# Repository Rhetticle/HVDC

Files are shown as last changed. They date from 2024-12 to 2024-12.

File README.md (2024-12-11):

# HVDC
High voltage DC arc lighter.

<p align="center">
  
  
</p>

<p align="center">
  
</p>

# Topology
HVDC uses a spark-gap style method of arc generation. The two 1uF 1.3kV capacitors are charged until around 600V at which point the 600V gas discharge tube breaks down and the capacitor energy is dumped into the final output transformer primary to generate a high voltage arc on the secondary. 

The first transformer is used to step up the 7.4V supply voltage to 1kV to charge the capacitors. This transformer is driven by a full H-bridge at a 50% duty cycle. Two sqaure wave gate signals are generated by an STM32 microcontroller and two half-bridge gate drivers are used to provide fast switching speeds on the MOSFETs.

HVDC also features a completely embedded battery charging/management system to charge the 2S Lipo battery directly from a micro USB cable.

# Hardware Details
* Microcontroller - STM32C011J6M6 (SOIC8)
* Gate Drivers (Half Bridge) - ADP3110AKRZ-RL (SOIC8)
* Battery Charger - BQ25306RTER (16-WQFN)

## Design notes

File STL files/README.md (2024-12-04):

# Casing
The casing for HVDC was modelled in Fusion 360 and is comprised of three parts namely the bottom piece, top piece and isolating plate. The plate isolates the battery from the potentially high voltage of the output capacitors.

## Casing - Bottom

<p align="center">
  
</p>

## Casing - Top

<p align="center">
  
</p>

# Transformer Insulator

<p align="center">
  
</p>

A insulator was made to hold the transformer to be potted in epoxy resin. As the arc distance of the transformer pins is shorter then the final air gap of the device, the transformer pins needed to be isolated from each other.
Standard self-leveling craft resin was used to achieve this

<p align="center">
  
</p>

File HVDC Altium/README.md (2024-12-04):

# HVDC Altium

The PCB used in HVDC was created in Altium Designer and manufactured by JLCPCB. The PCB is a standard 2 layer board 1.6mm thick.




# PCB
This PCB has a plane on top for the 7.4V rail and a ground plane on the bottom layer. Note that the power plane does not extend past the charging transformer in order to reduce switching noise being induced into the plane.

As this design mixes high voltage pulses and digital electronics, lots of decoupling was needed. Extra decoupling capacitors were added to the STM32, gate drivers, 3V3 LDO regulator and battery charger to ensure all voltage supply rails remain relatively stable while the device is in use. There is also an array of 8 1uF shunt capacitors to shunt the kickback from the charging transformer primary from putting too much noise onto the main 7.4V rail (During operation this rail was measured to have around 800mV peak ripple). Note this array is placed as close a possible to the transformer primary coil.

Two 1M ohm 1W bleed resistors are present in order to ensure the capacitors are always discharged when the device is not in operation and prevents capacitors from being partially charged from previous use.

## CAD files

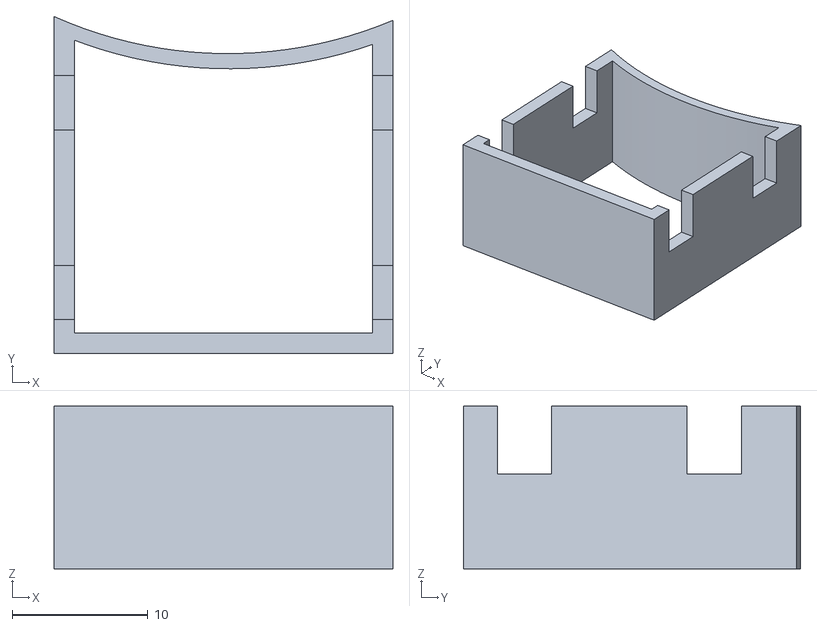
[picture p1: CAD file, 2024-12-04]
STL files/Transformer Insulator no bottom.stl
25.0 x 24.9 x 12.0

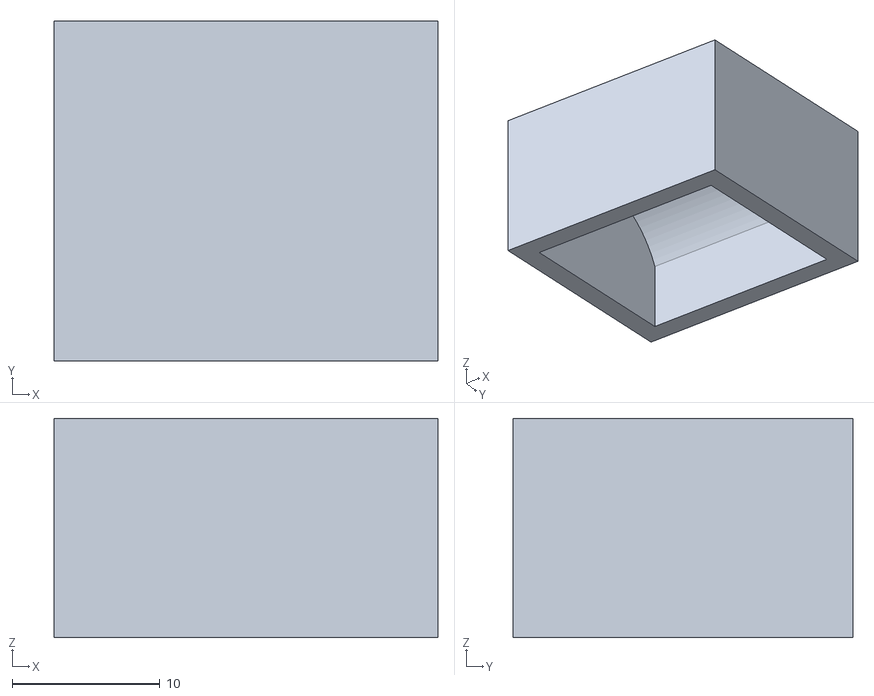
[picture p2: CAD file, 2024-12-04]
STL files/Insulator Cover.stl
26.0 x 23.0 x 14.8

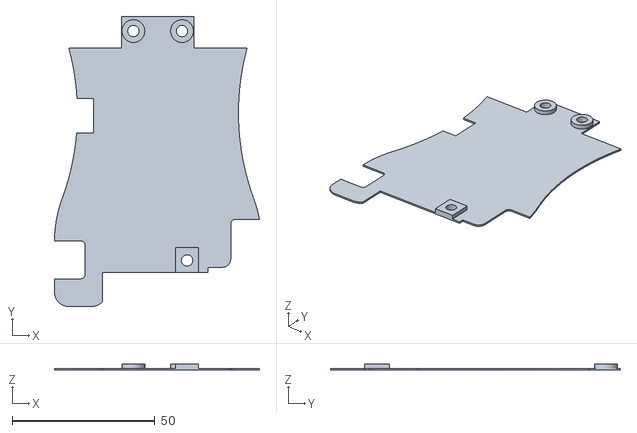
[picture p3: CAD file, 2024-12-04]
STL files/HVDC Isolating Plate.stl
71.7 x 101.5 x 2.19

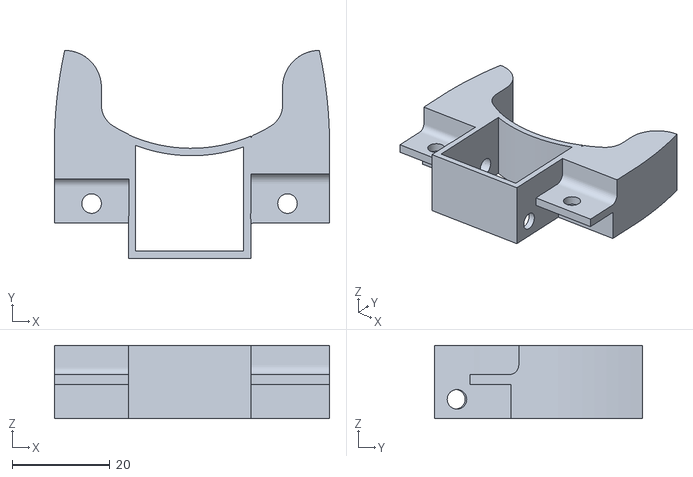
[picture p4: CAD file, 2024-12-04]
STL files/Transformer Insulator for epoxy.stl
56.2 x 42.5 x 15.0

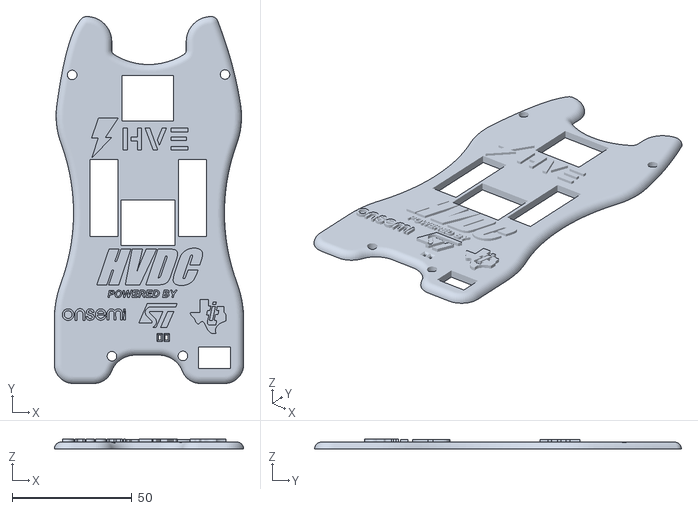
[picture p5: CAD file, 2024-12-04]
STL files/HVDC Top.stl
79.0 x 153.0 x 4.30

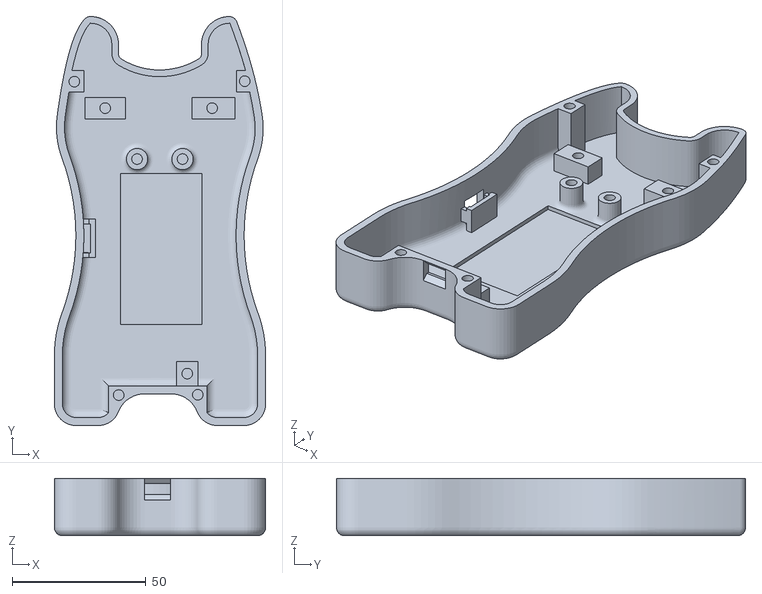
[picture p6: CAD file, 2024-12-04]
STL files/HVDC Bottom.stl
79.0 x 153.0 x 21.5

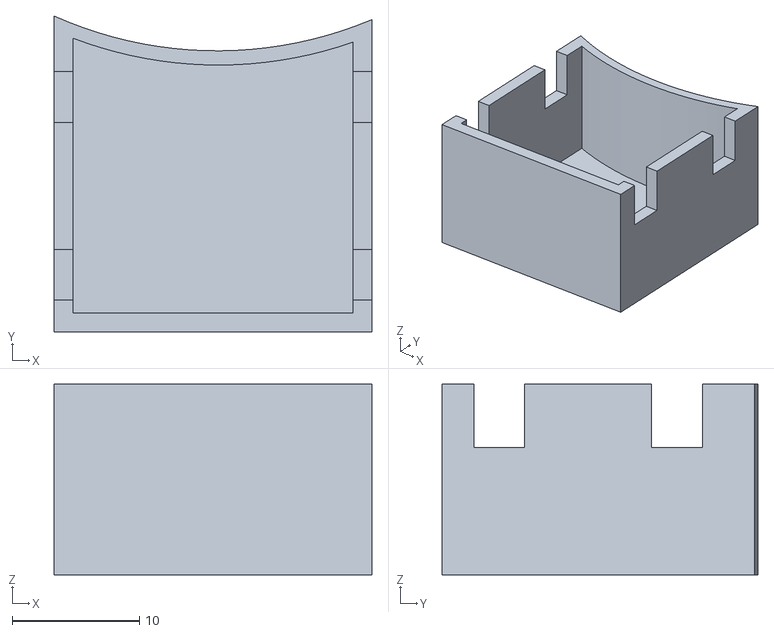
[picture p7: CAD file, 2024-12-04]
STL files/Transformer Insulator.stl
25.0 x 24.9 x 15.0
